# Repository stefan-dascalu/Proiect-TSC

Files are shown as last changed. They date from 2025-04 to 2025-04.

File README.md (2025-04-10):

Dascalu Stefan-Nicolae 331CA
# Proiect-TSC
## Implementare:

- **Implementarea Schemei Electrice:**
  - Am implementat schema electrica exact conform modelului primit.
  - Am efectuat o **verificare a regulilor electrice (ERC)**; desi am intampinat cateva avertismente, le-am revizuit si considerat necritice.

- **Designul PCB:**
  - Dupa finalizarea schemei, am incarcat designul in mediul PCB.
  - Toate componentele au fost amplasate pe **TOP layer** conform ghidurilor de layout.
  - Pentru a asigura **proper grounding** si **signal integrity**, am creat un **GND plane** atat pe TOP layer, cat si pe BOTTOM layer.
  - Am verificat toate constrangerile de design, iar rutarea a fost finalizata cu o rata de succes de 99,6%.
  - In timpul designului PCB, am intampinat si rezolvat erori de tip "airwire unrouted".

- **Fisiere de Productie:**
  - Am generat fisierele **Gerber**, **Pick and Place** si **BOM**.

- **Modelul 3D:**
  - Modelul 3D al dispozitivului a fost implementat.

## Imagine 3D
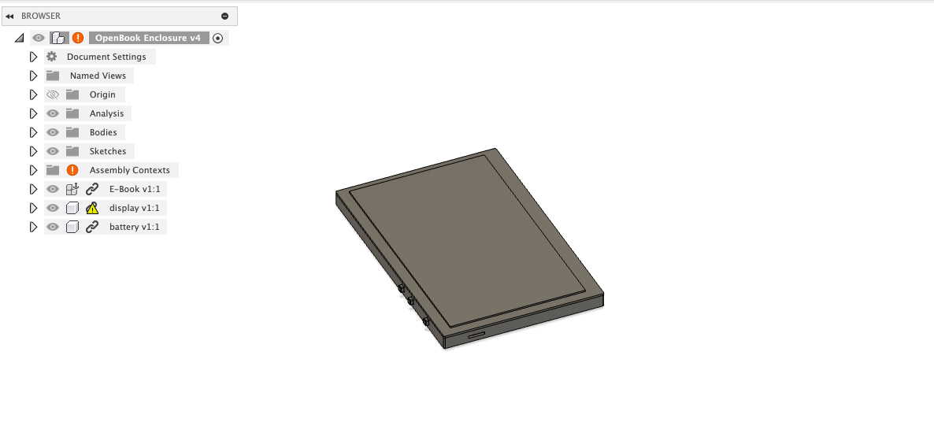
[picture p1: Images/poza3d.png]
Imagine 3D


## Diagrama bloc a proiectului:

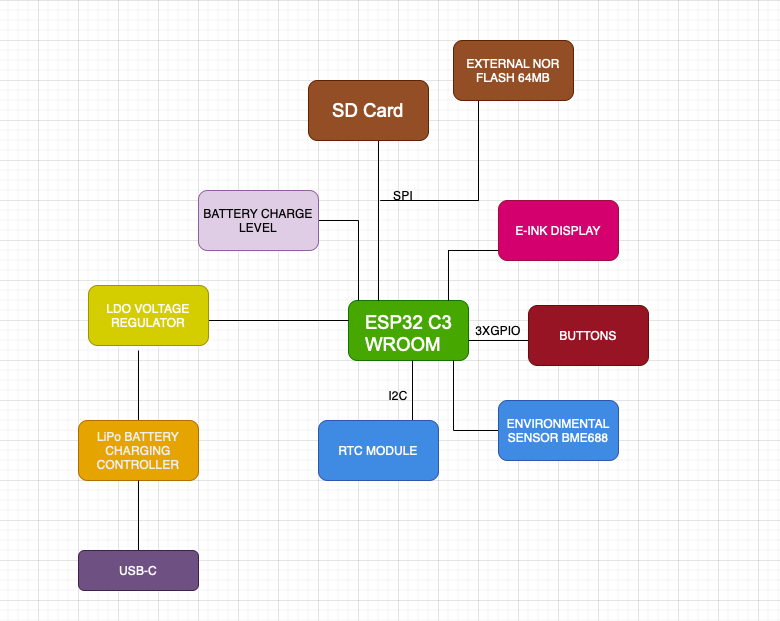
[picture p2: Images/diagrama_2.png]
Diagrama bloc


## Descriere Hardware si Asignarea Pinilor pe ESP32-C6

- **ESP32-C6-WROOM-1-N8 (Microcontroler Principal)**
  - Microcontrolerul ofera suport pentru WiFi 6, Bluetooth 5 LE si dispune de un nucleu RISC-V ce functioneaza pana la 160 MHz.
  - Interfetele disponibile includ SPI, I2C, UART si GPIO, fiind baza pentru conectarea celorlalte module.

- **BME688 (Senzor Ambiental)**
  - Maseaza temperatura, umiditatea, presiunea atmosferica si calitatea aerului.
  - Interfata: I2C
  - Pini utilizati: SDA -> IO21, SCL -> IO22
  - Alegerea acestor pini se face pentru a beneficia de o comunicatie I2C rapida si fiabila.

- **DS3231SN (Real-Time Clock)**
  - Asigura cronometrare de inalta precizie, chiar si in lipsa alimentarii principale.
  - Interfata: I2C (se partajeaza cu BME688)
  - Pini utilizati: SCL -> IO22, SDA -> IO21, INT_RTC -> IO8, 32KHZ -> IO1, RTC_RST -> IO18
  - Acesti pini asigura functii suplimentare de intrerupere si reset pentru modulul RTC.

- **Afisaj E-Ink (7.5 inch)**
  - Afisajul ofera o rezolutie de 800 x 480 pixeli si functioneaza prin interfata SPI.
  - Pini utilizati: EPD_CS -> IO10, EPD_DC -> IO5, EPD_RST -> IO23, EPD_BUSY -> IO3 (EPD_BUSY este partajat cu MISO)
  - Linile MOSI si SCK sunt partajate cu modulul SD, permitand optimizarea numarului de pini utilizati.

- **Modul SD Card**
  - Permite stocarea locala a datelor, cum ar fi e-bookurile sau firmware-ul.
  - Interfata: SPI
  - Pini utilizati: SS_SD -> IO4, MOSI -> IO7, MISO -> IO2, SCK -> IO6
  - Aceste asignari asigura sincronizarea corecta a datelor pe interfata SPI.

- **Memorie Externa Flash (W25Q512JVEIQ, 64MB)**
  - Memoria flash externa este utilizata pentru stocarea firmware-ului si a datelor importante.
  - Interfata: SPI
  - Pini utilizati: FLASH_CS -> IO12 (MOSI, MISO si SCK sunt partajate cu modulul SD)
  
- **Interfata USB/SD**
  - Asigura alimentarea si transferul de date prin USB.
  - Pini utilizati: USB_D+ -> IO13, USB_D- -> IO12

- **Butoane Boot si Reset**
  - Permit accesul la modul boot si efectuarea unui reset hardware.
  - Pini utilizati: IO/BOOT -> IO9, RESET -> un pin dedicat (conform schemei)

- **Sistem de Alimentare si Management**
  - Bateria Li-Po (3.7V, 2500mAh) alimenteaza sistemul.
  - Controlerul de incarcare MCP73831 gestioneaza incarcarea prin USB-C.
  - Monitorizarea bateriei se realizeaza cu MAX17048, care comunica prin I2C (reutilizand SDA/IO21 si SCL/IO22).
  - Regulatorul LDO XC6220A331MR-G furnizeaza 3.3V stabile pentru toate modulele.
  
- **Conector USB-C**
  - Principalul conector pentru alimentare si transfer de date, protejat de circuit ESD.

- **Conector Qwiic/Stemma QT**
  - Permite extinderea usoara a sistemului cu module suplimentare I2C.
  - Utilizeaza acelasi bus I2C (SDA -> IO21, SCL -> IO22) ca si senzorii si modulul RTC.

## BOM:
| Component | Link |
|---|---|
| ADAFRUIT_LEDCHIP-LED0603 | [Click here](https://www.snapeda.com/parts/KP-1608SURCK/Kingbright/view-part/?ref=search&t=LED%200603) |
| SJ | [Click here](https://grabcad.com/library/solder-jumpers-1) |
| 112ATAARR03 | [Click here](https://www.snapeda.com/parts/112A-TAAR-R03/Attend/view-part/) |
| RCL_CPOL-EUCT3528 | [Click here](https://grabcad.com/library/tantalum-smd-capacitor-type-b-3528-1) |
| BUTTON_CUSYOMV1 | [Click here](https://www.snapeda.com/search/?q=EVQP7L01P&search-type=parts) |
| DS3231SN# | [Click here](https://www.snapeda.com/parts/DS3231SN%23/Analog%20Devices/view-part/?ref=search&t=DS3231SN%23) |
| ESP32-C6-WROOM-1-N8 | [Click here](https://www.snapeda.com/parts/ESP32-C6-WROOM-1-N8/Espressif%20Systems/view-part/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) |
| 744043680 | [Click here](https://eu.mouser.com/ProductDetail/Wurth-Elektronik/744043680?qs=PGXP4M47uW6VkZq%252BkzjrHA%3D%3D) |
| BD5229G-TR | [Click here](https://www.snapeda.com/parts/BD5229G-TR/Rohm/view-part/?ref=search&t=BD5229G-TR) |
| ESP32_WROVER_BME680_BME680 | [Click here](https://www.snapeda.com/parts/BME680/Bosch%20Sensortec/view-part/?ref=search&t=bme680) |
| ESP32_WROVER_EAGLE-LTSPICE_R | [Click here](https://componentsearchengine.com/part-view/R0402%201%25%20100%20K%20(RC0402FR-07100KL)/YAGEO) |
| ESP32_WROVER_SPARKFUN-DISCRETESEMI_MOSFET_PCH | [Click here](https://componentsearchengine.com/part-view/DMG2305UX-7/Diodes%20Incorporated) |
| ESP32_WROVER_SPARKFUN-IC-POWER_MCP73831 | [Click here](https://componentsearchengine.com/part-view/MCP73831T-2ACI%2FOT/Microchip) |
| FH34SRJ-24S-0.5SH_99_ | [Click here](https://componentsearchengine.com/part-view/FH34SRJ-24S-0.5SH(99)/Hirose) |
| TP | - |
| SI1308EDL-T1-GE3 | [Click here](https://www.snapeda.com/parts/SI1308EDL-T1-GE3/Vishay/view-part/) |
| ESP32_WROVER_AVX---SD0805S020S1R0_AVX_SD0805S020S1R0_0_0  | [Click here](https://componentsearchengine.com/part-view/SD0805S020S1R0/Kyocera%20AVX) |
| CPH3225A | [Click here](https://www.snapeda.com/parts/CPH3225A/Seiko/view-part/) |
| MAX17048G+T10 | [Click here](https://www.snapeda.com/parts/MAX17048G+T10/Analog%20Devices/view-part/) |
| MBR0530 | [Click here](https://www.snapeda.com/parts/MBR0530/Onsemi/view-part/) |
| PGB1010603MR | [Click here](https://www.snapeda.com/parts/PGB1010603MR/Littelfuse/view-part/) |
| QWIIC_RIGHT_ANGLE (QWIIC_CONNECTORJS-1MM) | [Click here](https://www.snapeda.com/parts/PRT-14417/SparkFun/view-part/) |
| SAMACSYS_PARTS_USB4110-GF-A | [Click here](https://www.snapeda.com/parts/USB4110-GF-A./Global%20Connector%20Technology/view-part/) |
| USBLC6-2SC6Y | [Click here](https://www.snapeda.com/parts/USBLC6-2SC6Y/STMicroelectronics/view-part/?ref=dk&t=USBLC6-2SC6Y&con_ref=None) |
| W25Q512JVEIQ | [Click here](https://www.snapeda.com/parts/W25Q512JVEIQ/Winbond%20Electronics/view-part/?ref=search&t=W25Q512JVEIQ) |
| XC6220A331MR-G | [Click here](https://ro.mouser.com/ProductDetail/Torex-Semiconductor/XC6220A331MR-G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) |

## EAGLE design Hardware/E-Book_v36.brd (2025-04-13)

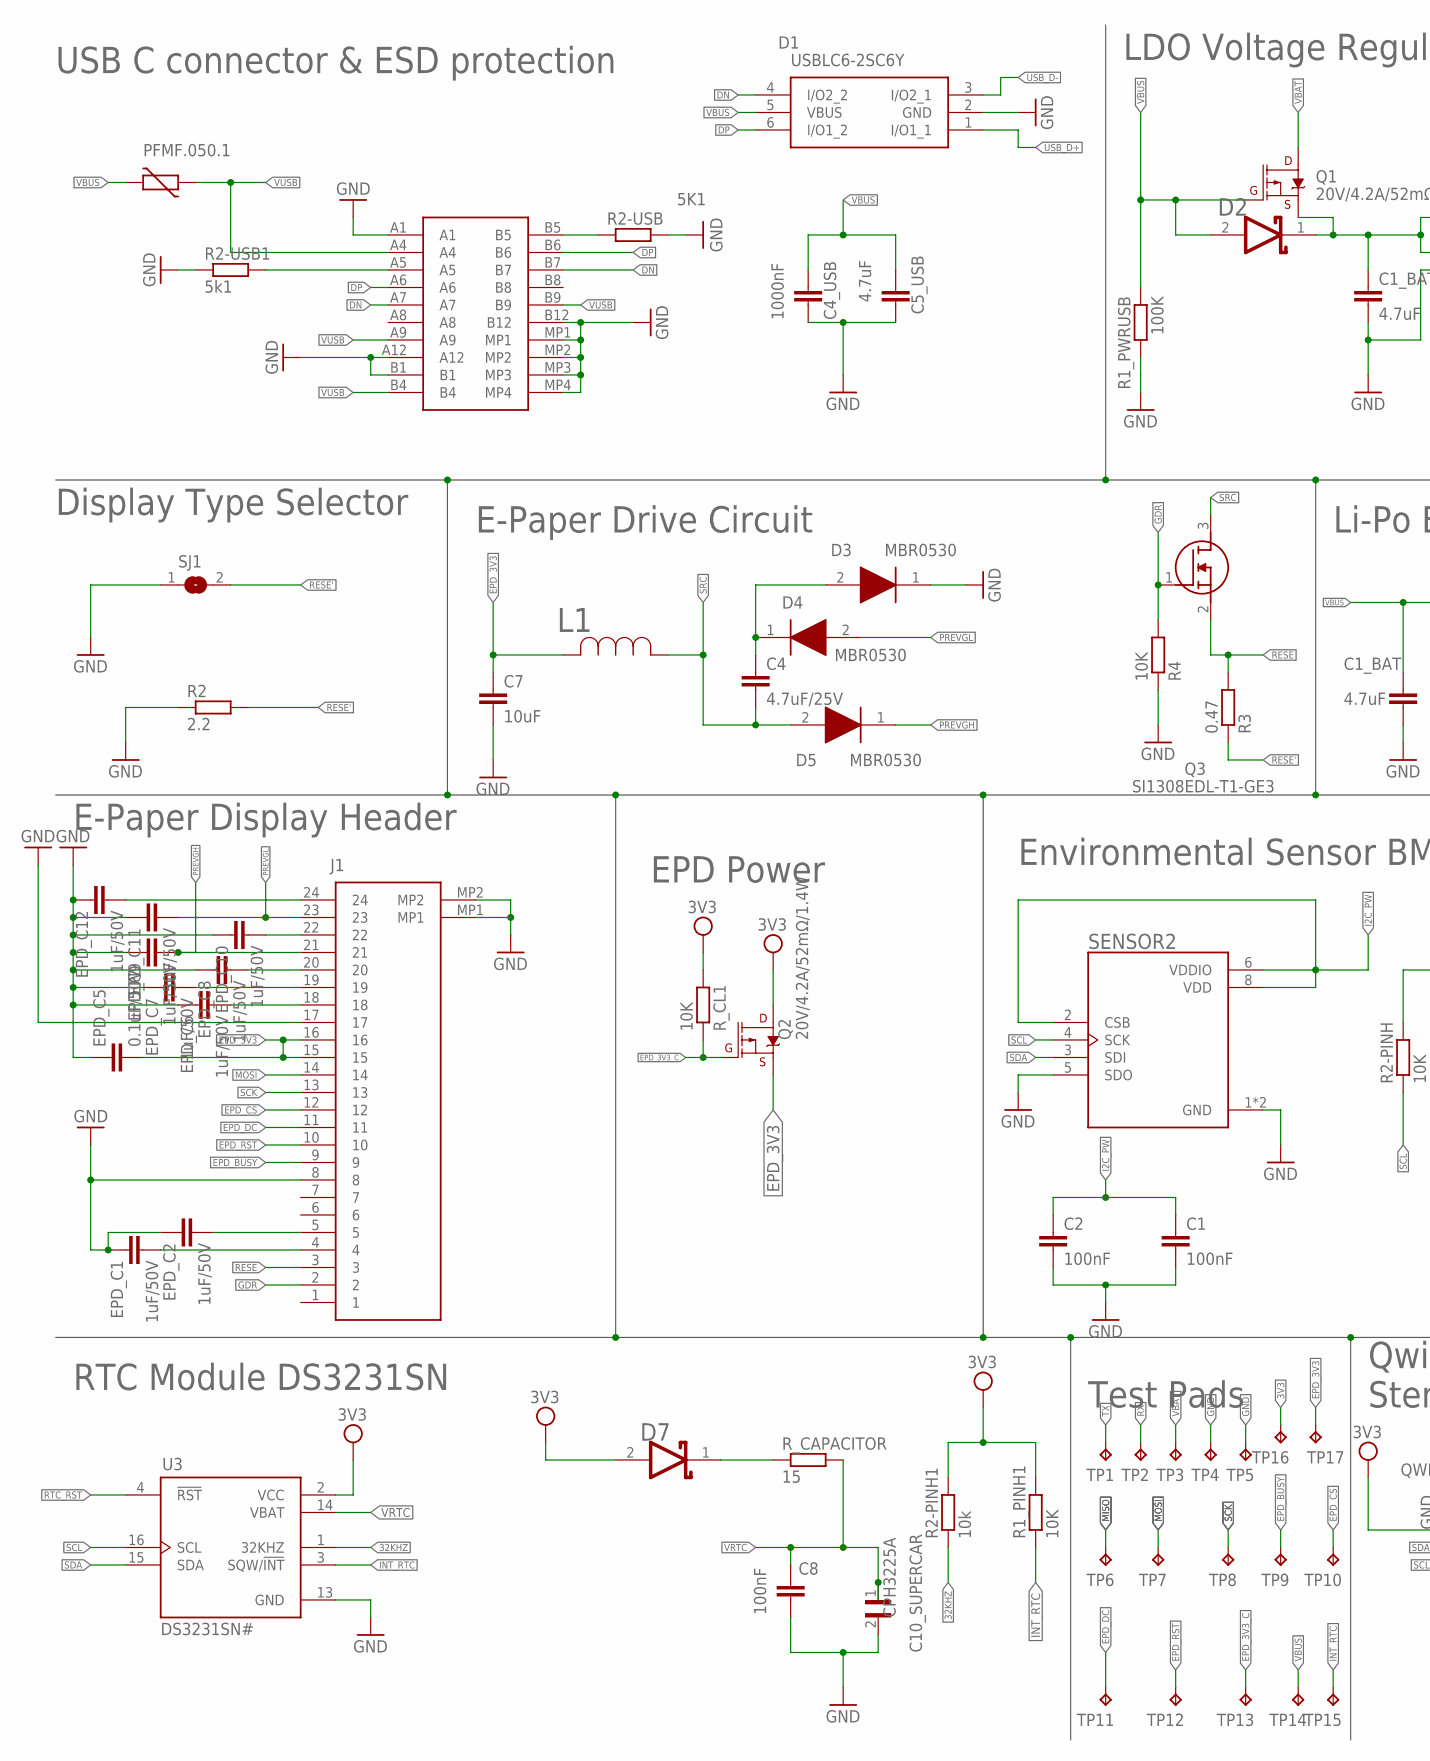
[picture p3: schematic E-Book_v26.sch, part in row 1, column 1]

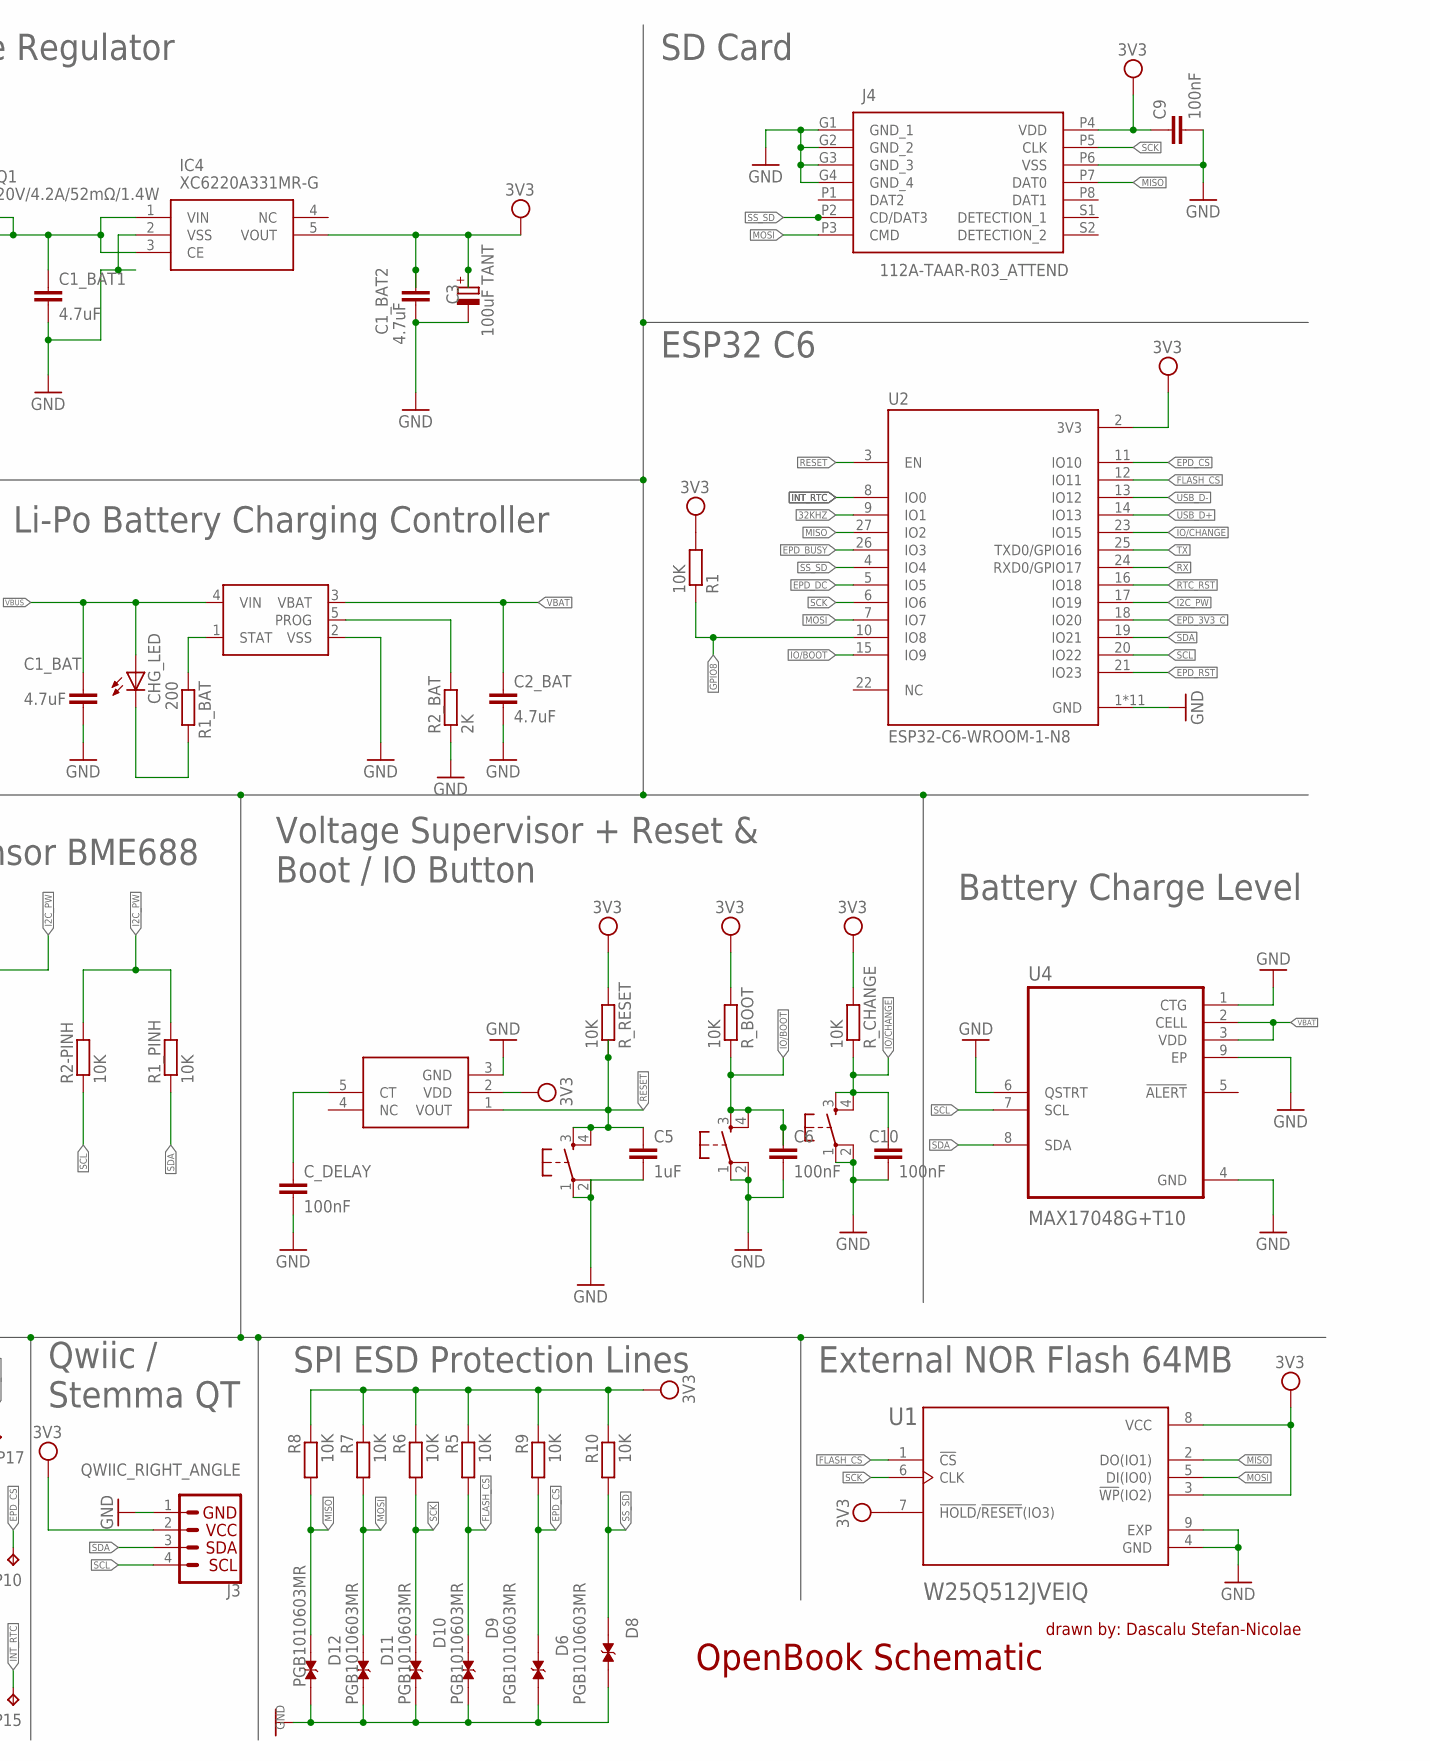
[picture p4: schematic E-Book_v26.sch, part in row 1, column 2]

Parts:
C1, C2, C6, C8, C9, C10: 100nF; ESP32_WROVER_EAGLE-LTSPICE_C0402
C1_BAT, C2_BAT: 4.7uF; ESP32_WROVER_EAGLE-LTSPICE_C0402
C1_BAT1, C1_BAT2, C5_USB: 4.7uF; EAGLE-LTSPICE_C0402
C3: 100uF TANT; RCL_CT3528
C4: 4.7uF/25V; ESP32_WROVER_EAGLE-LTSPICE_C0402
C4_USB: 1000nF; EAGLE-LTSPICE_C0402
C5: 1uF; ESP32_WROVER_EAGLE-LTSPICE_C0402
C7: 10uF; ESP32_WROVER_EAGLE-LTSPICE_C0402
C10_SUPERCAR: CPH3225A; CAPCP3225X100N
CHG_LED: ADAFRUIT_LEDCHIP-LED0603; ADAFRUIT_CHIP-LED0603
C_DELAY: 100nF; ESP32_WROVER_EAGLE-LTSPICE_C0402
D1: USBLC6-2SC6Y; SOT95P280X145-6N
D2, D7: ESP32_WROVER_AVX---SD0805S020S1R0_AVX_SD0805S020S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; ESP32_WROVER_AVX---SD0805S020S1R0_AVX_SD0805S020S1R0_0
D3, D4, D5: MBR0530; SOD3716X135N
D6, D8, D9, D10, D11, D12: PGB1010603MR; DIOC1608X36N
EPD_C1, EPD_C2, EPD_C6, EPD_C7, EPD_C8, EPD_C9, EPD_C10, EPD_C11, EPD_C12: 1uF/50V; ESP32_WROVER_EAGLE-LTSPICE_C0402
EPD_C5: 0.1uF/50V; ESP32_WROVER_EAGLE-LTSPICE_C0402
IC1: BD5229G-TR; SOT95P280X125-5N
IC4: XC6220A331MR-G; SOT95P280X120-5N
J1: FH34SRJ-24S-0.5SH_99_; FH34SRJ24S05SH99
J2: SAMACSYS_PARTS_USB4110-GF-A; SAMACSYS_PARTS_USB4110GFA
J3: QWIIC_RIGHT_ANGLE; JST04_1MM_RA
J4: 112A-TAAR-R03_ATTEND; 112ATAARR03ATTEND
L1: 744043680IND_4828-WE-TPC_WRE; IND_4828-WE-TPC_WRE
MCP73831: ESP32_WROVER_SPARKFUN-IC-POWER_MCP73831; ESP32_WROVER_SPARKFUN-IC-POWER_SOT23-5
PFMF.050.1: ESP32C6_VARISTORCN1812; ESP32C6_VARISTOR_CT/CN1812
Q1, Q2: 20V/4.2A/52mΩ/1.4W; ESP32_WROVER_SPARKFUN-DISCRETESEMI_SOT23-3
Q3: SI1308EDL-T1-GE3; SOT65P210X110-3N
R1, R1_PINH, R1_PINH1, R2-PINH, R4, R5, R6, R7, R8, R9, R10: 10K; ESP32_WROVER_EAGLE-LTSPICE_R0402
R1_BAT: 200; ESP32_WROVER_EAGLE-LTSPICE_R0402
R1_PWRUSB: 100K; ESP32_WROVER_EAGLE-LTSPICE_R0402
R2: 2.2; ESP32_WROVER_EAGLE-LTSPICE_R0402
R2-PINH1: 10k; ESP32_WROVER_EAGLE-LTSPICE_R0402
R2-USB: 5K1; ESP32_WROVER_EAGLE-LTSPICE_R0402
R2-USB1: 5k1; ESP32_WROVER_EAGLE-LTSPICE_R0402
R2_BAT: 2K; ESP32_WROVER_EAGLE-LTSPICE_R0402
R3: 0.47; ESP32_WROVER_EAGLE-LTSPICE_R0402
RESET_BUTTON: BUTTON_CUSYOMV1; MYBUTTON
R_BOOT: 10K; ESP32_WROVER_EAGLE-LTSPICE_R0402
R_CAPACITOR: 15; ESP32_WROVER_EAGLE-LTSPICE_R0402
R_CHANGE: 10K; ESP32_WROVER_EAGLE-LTSPICE_R0402
R_CL1: 10K; ESP32_WROVER_EAGLE-LTSPICE_R0402
R_RESET: 10K; ESP32_WROVER_EAGLE-LTSPICE_R0402
SENSOR2: ESP32_WROVER_BME680_BME680; ESP32_WROVER_BME680_PSON80P300X300X100-8N
SJ1: SJ
TP1, TP2, TP3, TP4, TP5, TP6, TP7, TP8, TP9, TP10, TP11, TP12, TP13, TP14, TP15, TP16, TP17: TPTP20R; TP20R
U1: W25Q512JVEIQ; SON127P600X800X80-9N
U2: ESP32-C6-WROOM-1-N8; XCVR_ESP32-C6-WROOM-1-N8
U3: DS3231SN#; SOIC127P1032X265-16N
U4: MAX17048G+T10; SON50P200X200X80-9N
U$1, U$3: BUTTON_CUSYOMV1; MYBUTTON

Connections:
3V3: C1_BAT2.1, C3.+, C9.1, D7.2 (ANODE), IC1.2 (VDD), IC4.5 (VOUT), J3.2, J4.P4 (VDD), Q2.3 (D), R1.2, R1_PINH1.2, R2-PINH1.2, R5.1, R6.1, R7.1, R8.1, R9.1, R10.1, R_BOOT.2, R_CHANGE.2, R_CL1.2, R_RESET.2, TP16.TP, U1.3 (!WP!(IO2)), U1.7 (!HOLD!/!RESET!(IO3)), U1.8 (VCC), U2.2 (3V3), U3.2 (VCC)
32KHZ: R2-PINH1.1, U2.9 (IO1), U3.1 (32KHZ)
DN: D1.4 (I/O2_2), J2.A7, J2.B7
DP: D1.6 (I/O1_2), J2.A6, J2.B6
EPD_3V3: C7.1, EPD_C5.2, J1.15, J1.16, L1.2, Q2.2 (S), TP17.TP
EPD_3V3_C: Q2.1 (G), R_CL1.1, TP13.TP, U2.18 (IO20)
EPD_BUSY: J1.9, TP9.TP, U2.26 (IO3)
EPD_CS: D6.1, J1.12, R9.2, TP10.TP, U2.11 (IO10)
EPD_DC: J1.11, TP11.TP, U2.5 (IO5)
EPD_RST: J1.10, TP12.TP, U2.21 (IO23)
FLASH_CS: D9.1, R5.2, U1.1 (!CS), U2.12 (IO11)
GDR: J1.2, Q3.1 (G), R4.2
GND: C1.2, C1_BAT.2, C1_BAT1.2, C1_BAT2.2, C2.2, C2_BAT.2, C3.-, C4_USB.2, C5.2, C5_USB.2, C6.2, C7.2, C8.2, C9.2, C10.2, C10_SUPERCAR.2, C_DELAY.2, D1.2 (GND), D3.1 (K), D6.2, D8.2, D9.2, D10.2, D11.2, D12.2, EPD_C1.1, EPD_C2.1, EPD_C5.1, EPD_C6.1, EPD_C7.1, EPD_C8.1, EPD_C9.1, EPD_C10.1, EPD_C11.1, EPD_C12.1, IC1.3 (GND), IC4.2 (VSS), J1.8, J1.17, J1.MP1, J1.MP2, J2.A1, J2.A12, J2.B1, J2.B12, J2.MP1, J2.MP2, J2.MP3, J2.MP4, J3.1, J4.G1 (GND_1), J4.G2 (GND_2), J4.G3 (GND_3), J4.G4 (GND_4), J4.P6 (VSS), MCP73831.2 (VSS), R1_PWRUSB.2, R2.1, R2-USB.2, R2-USB1.1, R2_BAT.1, R4.1, RESET_BUTTON.1, RESET_BUTTON.2, SENSOR2.1 (GND), SENSOR2.5 (SDO), SENSOR2.7 (GND), SJ1.1, TP4.TP, TP5.TP, U1.4 (GND), U1.9 (EXP), U2.1 (GND), U2.28 (GND), U2.29_1 (GND), U2.29_2 (GND), U2.29_3 (GND), U2.29_4 (GND), U2.29_5 (GND), U2.29_6 (GND), U2.29_7 (GND), U2.29_8 (GND), U2.29_9 (GND), U3.13 (GND), U4.1 (CTG), U4.4 (GND), U4.6 (QSTRT), U4.9 (EP), U$1.1, U$1.2, U$3.1, U$3.2
GPIO8: R1.1, U2.10 (IO8)
I2C_PW: C1.1, C2.1, R1_PINH.2, R2-PINH.2, SENSOR2.2 (CSB), SENSOR2.6 (VDDIO), SENSOR2.8 (VDD), U2.17 (IO19)
INT_RTC: R1_PINH1.1, TP15.TP, U2.8 (IO0), U3.3 (SQW/!INT)
IO/BOOT: C6.1, R_BOOT.1, U2.15 (IO9), U$3.3, U$3.4
IO/CHANGE: C10.1, R_CHANGE.1, U2.23 (IO15), U$1.3, U$1.4
MISO: D12.1, J4.P7 (DAT0), R8.2, TP6.TP, U1.2 (DO(IO1)), U2.27 (IO2)
MOSI: D11.1, J1.14, J4.P3 (CMD), R7.2, TP7.TP, U1.5 (DI(IO0)), U2.7 (IO7)
unnamed: J2.B5, R2-USB.1
unnamed: J2.A5, R2-USB1.2
unnamed: CHG_LED.C, R1_BAT.2
unnamed: EPD_C1.2, J1.4
unnamed: MCP73831.5 (PROG), R2_BAT.2
unnamed: EPD_C2.2, J1.5
unnamed: MCP73831.1 (STAT), R1_BAT.1
unnamed: EPD_C6.2, J1.18
unnamed: EPD_C7.2, J1.19
unnamed: EPD_C8.2, J1.20
unnamed: EPD_C10.2, J1.22
unnamed: EPD_C12.2, J1.24
unnamed: C_DELAY.1, IC1.5 (CT)
unnamed: C1_BAT1.1, D2.1 (CATHODE), IC4.1 (VIN), IC4.3 (CE), Q1.2 (S)
unnamed: C4.1, D3.2 (A), D4.1 (K)
unnamed: D7.1 (CATHODE), R_CAPACITOR.1
PREVGH: D5.1 (K), EPD_C9.2, J1.21
PREVGL: D4.2 (A), EPD_C11.2, J1.23
RESE: J1.3, Q3.2 (S), R3.2
RESE': R2.2, R3.1, SJ1.2
RESET: C5.1, IC1.1 (VOUT), RESET_BUTTON.3, RESET_BUTTON.4, R_RESET.1, U2.3 (EN)
RTC_RST: U2.16 (IO18), U3.4 (!RST)
RX: TP2.TP, U2.24 (RXD0/GPIO17)
SCK: D10.1, J1.13, J4.P5 (CLK), R6.2, TP8.TP, U1.6 (CLK), U2.6 (IO6)
SCL: J3.4, R2-PINH.1, SENSOR2.4 (SCK), U2.20 (IO22), U3.16 (SCL), U4.7 (SCL)
SDA: J3.3, R1_PINH.1, SENSOR2.3 (SDI), U2.19 (IO21), U3.15 (SDA), U4.8 (SDA)
SRC: C4.2, D5.2 (A), L1.1, Q3.3 (D)
SS_SD: D8.1, J4.P2 (CD/DAT3), R10.2, U2.4 (IO4)
TX: TP1.TP, U2.25 (TXD0/GPIO16)
USB_D+: D1.1 (I/O1_1), U2.14 (IO13)
USB_D-: D1.3 (I/O2_1), U2.13 (IO12)
VBAT: C2_BAT.1, MCP73831.3 (VBAT), Q1.3 (D), TP3.TP, U4.2 (CELL), U4.3 (VDD)
VBUS: C1_BAT.1, C4_USB.1, C5_USB.1, CHG_LED.A, D1.5 (VBUS), D2.2 (ANODE), MCP73831.4 (VIN), PFMF.050.1.2, Q1.1 (G), R1_PWRUSB.1, TP14.TP
VRTC: C8.1, C10_SUPERCAR.1, R_CAPACITOR.2, U3.14 (VBAT)
VUSB: J2.A4, J2.A9, J2.B4, J2.B9, PFMF.050.1.1

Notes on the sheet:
USB C connector & ESD protection
Display Type Selector
Test Pads
Qwiic / Stemma QT
External NOR Flash 64MB
drawn by: Dascalu Stefan-Nicolae
Battery Charge Level
OpenBook Schematic
EPD Power
Environmental Sensor BME688
SD Card
ESP32 C6
Li-Po Battery Charging Controller
E-Paper Display Header
SPI ESD Protection Lines
LDO Voltage Regulator
Voltage Supervisor + Reset & Boot / IO Button
E-Paper Drive Circuit
RTC Module DS3231SN


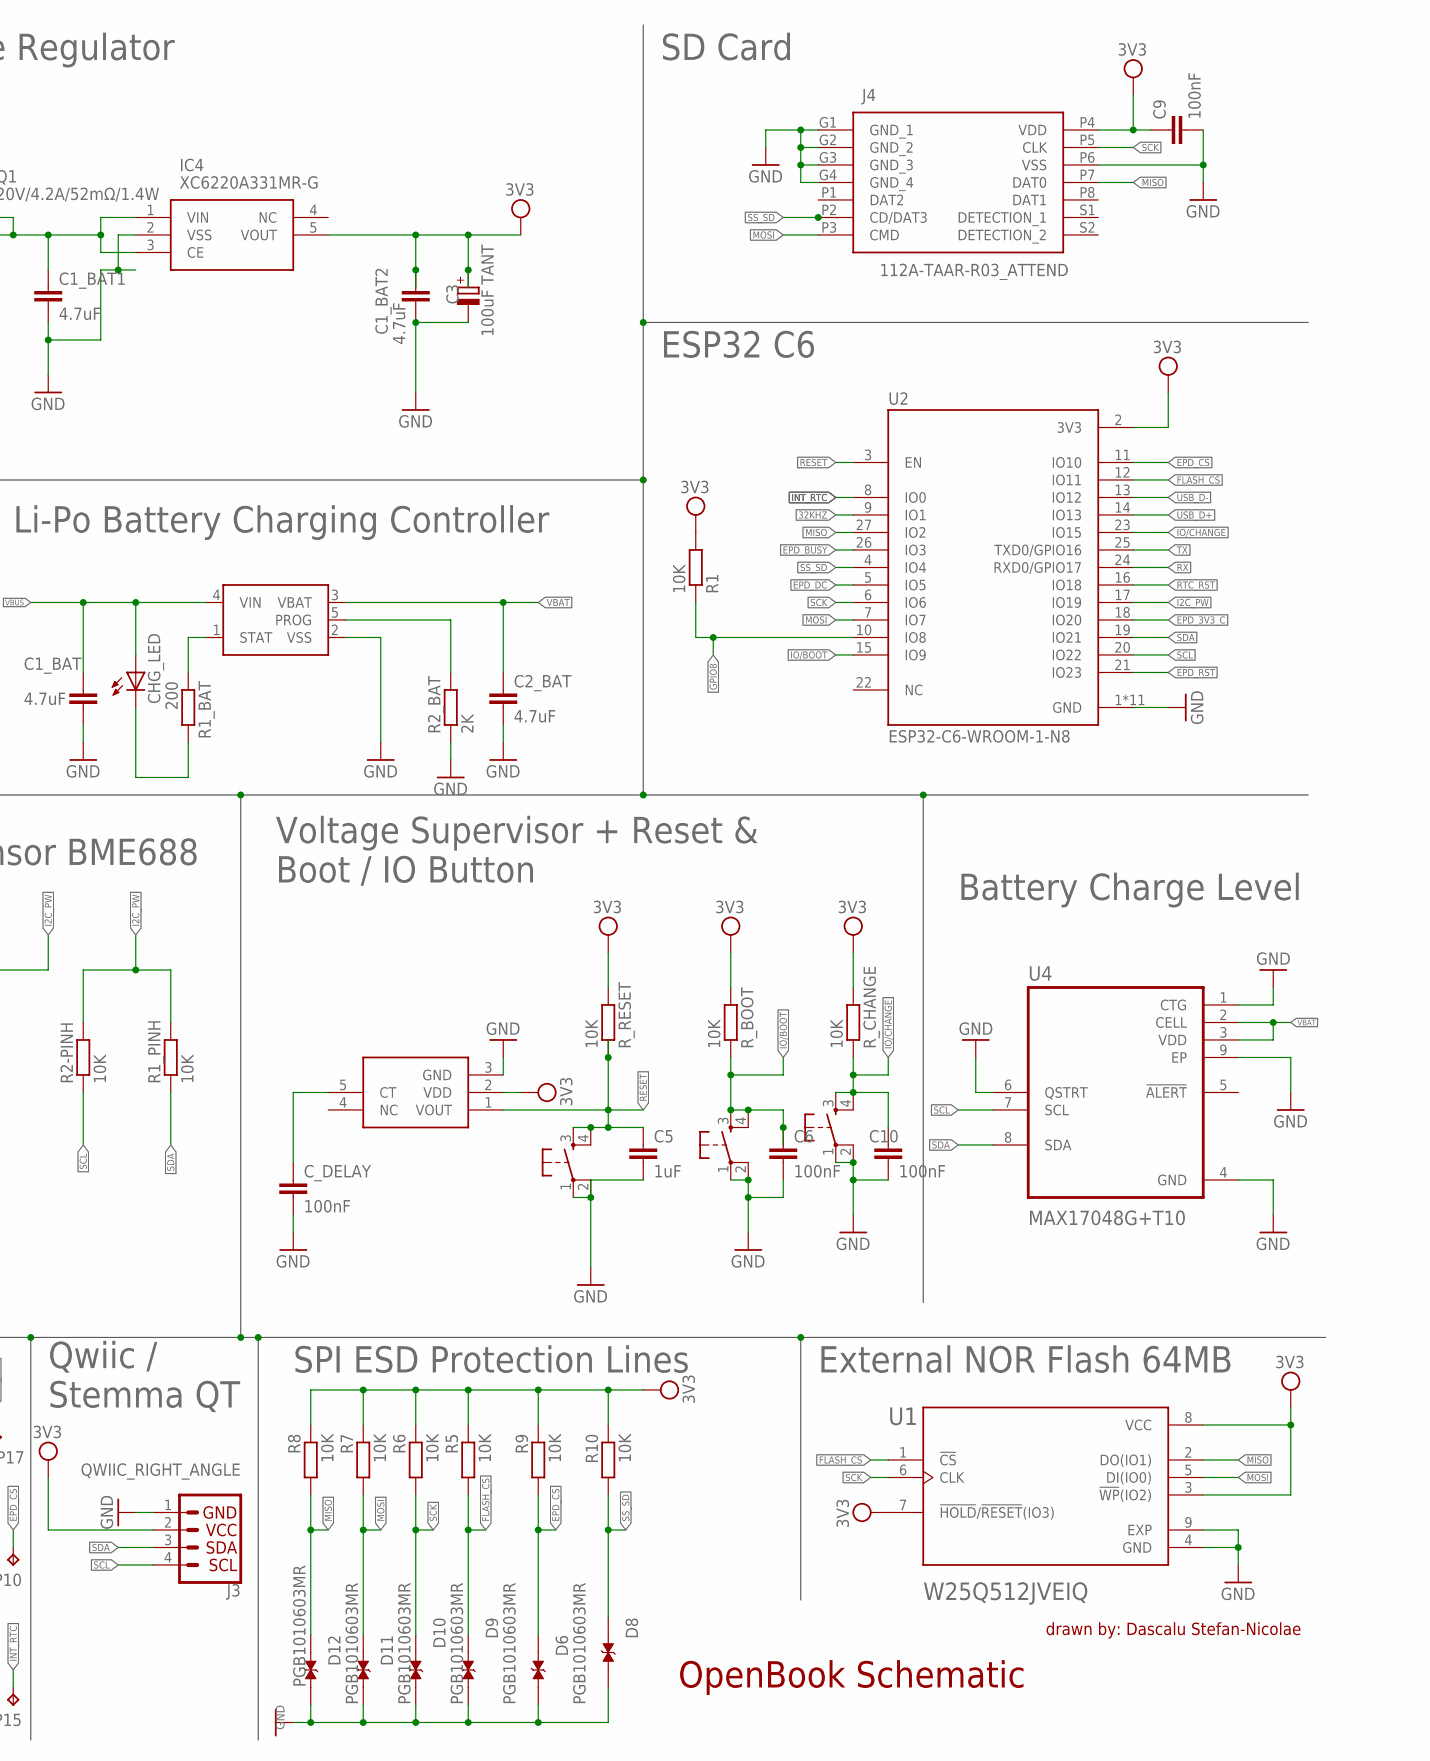
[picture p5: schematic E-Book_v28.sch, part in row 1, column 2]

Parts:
C1, C2, C6, C8, C9, C10: 100nF; ESP32_WROVER_EAGLE-LTSPICE_C0402
C1_BAT, C2_BAT: 4.7uF; ESP32_WROVER_EAGLE-LTSPICE_C0402
C1_BAT1, C1_BAT2, C5_USB: 4.7uF; EAGLE-LTSPICE_C0402
C3: 100uF TANT; RCL_CT3528
C4: 4.7uF/25V; ESP32_WROVER_EAGLE-LTSPICE_C0402
C4_USB: 1000nF; EAGLE-LTSPICE_C0402
C5: 1uF; ESP32_WROVER_EAGLE-LTSPICE_C0402
C7: 10uF; ESP32_WROVER_EAGLE-LTSPICE_C0402
C10_SUPERCAR: CPH3225A; CAPCP3225X100N
CHG_LED: ADAFRUIT_LEDCHIP-LED0603; ADAFRUIT_CHIP-LED0603
C_DELAY: 100nF; ESP32_WROVER_EAGLE-LTSPICE_C0402
D1: USBLC6-2SC6Y; SOT95P280X145-6N
D2, D7: ESP32_WROVER_AVX---SD0805S020S1R0_AVX_SD0805S020S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; ESP32_WROVER_AVX---SD0805S020S1R0_AVX_SD0805S020S1R0_0
D3, D4, D5: MBR0530; SOD3716X135N
D6, D8, D9, D10, D11, D12: PGB1010603MR; DIOC1608X36N
EPD_C1, EPD_C2, EPD_C6, EPD_C7, EPD_C8, EPD_C9, EPD_C10, EPD_C11, EPD_C12: 1uF/50V; ESP32_WROVER_EAGLE-LTSPICE_C0402
EPD_C5: 0.1uF/50V; ESP32_WROVER_EAGLE-LTSPICE_C0402
IC1: BD5229G-TR; SOT95P280X125-5N
IC4: XC6220A331MR-G; SOT95P280X120-5N
J1: FH34SRJ-24S-0.5SH_99_; FH34SRJ24S05SH99
J2: SAMACSYS_PARTS_USB4110-GF-A; SAMACSYS_PARTS_USB4110GFA
J3: QWIIC_RIGHT_ANGLE; JST04_1MM_RA
J4: 112A-TAAR-R03_ATTEND; 112ATAARR03ATTEND
L1: 744043680IND_4828-WE-TPC_WRE; IND_4828-WE-TPC_WRE
MCP73831: ESP32_WROVER_SPARKFUN-IC-POWER_MCP73831; ESP32_WROVER_SPARKFUN-IC-POWER_SOT23-5
PFMF.050.1: ESP32C6_VARISTORCN1812; ESP32C6_VARISTOR_CT/CN1812
Q1, Q2: 20V/4.2A/52mΩ/1.4W; ESP32_WROVER_SPARKFUN-DISCRETESEMI_SOT23-3
Q3: SI1308EDL-T1-GE3; SOT65P210X110-3N
R1, R1_PINH, R1_PINH1, R2-PINH, R4, R5, R6, R7, R8, R9, R10: 10K; ESP32_WROVER_EAGLE-LTSPICE_R0402
R1_BAT: 200; ESP32_WROVER_EAGLE-LTSPICE_R0402
R1_PWRUSB: 100K; ESP32_WROVER_EAGLE-LTSPICE_R0402
R2: 2.2; ESP32_WROVER_EAGLE-LTSPICE_R0402
R2-PINH1: 10k; ESP32_WROVER_EAGLE-LTSPICE_R0402
R2-USB: 5K1; ESP32_WROVER_EAGLE-LTSPICE_R0402
R2-USB1: 5k1; ESP32_WROVER_EAGLE-LTSPICE_R0402
R2_BAT: 2K; ESP32_WROVER_EAGLE-LTSPICE_R0402
R3: 0.47; ESP32_WROVER_EAGLE-LTSPICE_R0402
RESET_BUTTON: BUTTON_CUSYOMV1; MYBUTTON
R_BOOT: 10K; ESP32_WROVER_EAGLE-LTSPICE_R0402
R_CAPACITOR: 15; ESP32_WROVER_EAGLE-LTSPICE_R0402
R_CHANGE: 10K; ESP32_WROVER_EAGLE-LTSPICE_R0402
R_CL1: 10K; ESP32_WROVER_EAGLE-LTSPICE_R0402
R_RESET: 10K; ESP32_WROVER_EAGLE-LTSPICE_R0402
SENSOR2: ESP32_WROVER_BME680_BME680; ESP32_WROVER_BME680_PSON80P300X300X100-8N
SJ1: SJ
TP1, TP2, TP3, TP4, TP5, TP6, TP7, TP8, TP9, TP10, TP11, TP12, TP13, TP14, TP15, TP16, TP17: TPTP20R; TP20R
U1: W25Q512JVEIQ; SON127P600X800X80-9N
U2: ESP32-C6-WROOM-1-N8; XCVR_ESP32-C6-WROOM-1-N8
U3: DS3231SN#; SOIC127P1032X265-16N
U4: MAX17048G+T10; SON50P200X200X80-9N
U$1, U$3: BUTTON_CUSYOMV1; MYBUTTON

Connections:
3V3: C1_BAT2.1, C3.+, C9.1, D7.2 (ANODE), IC1.2 (VDD), IC4.5 (VOUT), J3.2, J4.P4 (VDD), Q2.3 (D), R1.2, R1_PINH1.2, R2-PINH1.2, R5.1, R6.1, R7.1, R8.1, R9.1, R10.1, R_BOOT.2, R_CHANGE.2, R_CL1.2, R_RESET.2, TP16.TP, U1.3 (!WP!(IO2)), U1.7 (!HOLD!/!RESET!(IO3)), U1.8 (VCC), U2.2 (3V3), U3.2 (VCC)
32KHZ: R2-PINH1.1, U2.9 (IO1), U3.1 (32KHZ)
DN: D1.4 (I/O2_2), J2.A7, J2.B7
DP: D1.6 (I/O1_2), J2.A6, J2.B6
EPD_3V3: C7.1, EPD_C5.2, J1.15, J1.16, L1.2, Q2.2 (S), TP17.TP
EPD_3V3_C: Q2.1 (G), R_CL1.1, TP13.TP, U2.18 (IO20)
EPD_BUSY: J1.9, TP9.TP, U2.26 (IO3)
EPD_CS: D6.1, J1.12, R9.2, TP10.TP, U2.11 (IO10)
EPD_DC: J1.11, TP11.TP, U2.5 (IO5)
EPD_RST: J1.10, TP12.TP, U2.21 (IO23)
FLASH_CS: D9.1, R5.2, U1.1 (!CS), U2.12 (IO11)
GDR: J1.2, Q3.1 (G), R4.2
GND: C1.2, C1_BAT.2, C1_BAT1.2, C1_BAT2.2, C2.2, C2_BAT.2, C3.-, C4_USB.2, C5.2, C5_USB.2, C6.2, C7.2, C8.2, C9.2, C10.2, C10_SUPERCAR.2, C_DELAY.2, D1.2 (GND), D3.1 (K), D6.2, D8.2, D9.2, D10.2, D11.2, D12.2, EPD_C1.1, EPD_C2.1, EPD_C5.1, EPD_C6.1, EPD_C7.1, EPD_C8.1, EPD_C9.1, EPD_C10.1, EPD_C11.1, EPD_C12.1, IC1.3 (GND), IC4.2 (VSS), J1.8, J1.17, J1.MP1, J1.MP2, J2.A1, J2.A12, J2.B1, J2.B12, J2.MP1, J2.MP2, J2.MP3, J2.MP4, J3.1, J4.G1 (GND_1), J4.G2 (GND_2), J4.G3 (GND_3), J4.G4 (GND_4), J4.P6 (VSS), MCP73831.2 (VSS), R1_PWRUSB.2, R2.1, R2-USB.2, R2-USB1.1, R2_BAT.1, R4.1, RESET_BUTTON.1, RESET_BUTTON.2, SENSOR2.1 (GND), SENSOR2.5 (SDO), SENSOR2.7 (GND), SJ1.1, TP4.TP, TP5.TP, U1.4 (GND), U1.9 (EXP), U2.1 (GND), U2.28 (GND), U2.29_1 (GND), U2.29_2 (GND), U2.29_3 (GND), U2.29_4 (GND), U2.29_5 (GND), U2.29_6 (GND), U2.29_7 (GND), U2.29_8 (GND), U2.29_9 (GND), U3.13 (GND), U4.1 (CTG), U4.4 (GND), U4.6 (QSTRT), U4.9 (EP), U$1.1, U$1.2, U$3.1, U$3.2
GPIO8: R1.1, U2.10 (IO8)
I2C_PW: C1.1, C2.1, R1_PINH.2, R2-PINH.2, SENSOR2.2 (CSB), SENSOR2.6 (VDDIO), SENSOR2.8 (VDD), U2.17 (IO19)
INT_RTC: R1_PINH1.1, TP15.TP, U2.8 (IO0), U3.3 (SQW/!INT)
IO/BOOT: C6.1, R_BOOT.1, U2.15 (IO9), U$3.3, U$3.4
IO/CHANGE: C10.1, R_CHANGE.1, U2.23 (IO15), U$1.3, U$1.4
MISO: D12.1, J4.P7 (DAT0), R8.2, TP6.TP, U1.2 (DO(IO1)), U2.27 (IO2)
MOSI: D11.1, J1.14, J4.P3 (CMD), R7.2, TP7.TP, U1.5 (DI(IO0)), U2.7 (IO7)
unnamed: J2.B5, R2-USB.1
unnamed: J2.A5, R2-USB1.2
unnamed: CHG_LED.C, R1_BAT.2
unnamed: EPD_C1.2, J1.4
unnamed: MCP73831.5 (PROG), R2_BAT.2
unnamed: EPD_C2.2, J1.5
unnamed: MCP73831.1 (STAT), R1_BAT.1
unnamed: EPD_C6.2, J1.18
unnamed: EPD_C7.2, J1.19
unnamed: EPD_C8.2, J1.20
unnamed: EPD_C10.2, J1.22
unnamed: EPD_C12.2, J1.24
unnamed: C_DELAY.1, IC1.5 (CT)
unnamed: C1_BAT1.1, D2.1 (CATHODE), IC4.1 (VIN), IC4.3 (CE), Q1.2 (S)
unnamed: C4.1, D3.2 (A), D4.1 (K)
unnamed: D7.1 (CATHODE), R_CAPACITOR.1
PREVGH: D5.1 (K), EPD_C9.2, J1.21
PREVGL: D4.2 (A), EPD_C11.2, J1.23
RESE: J1.3, Q3.2 (S), R3.2
RESE': R2.2, R3.1, SJ1.2
RESET: C5.1, IC1.1 (VOUT), RESET_BUTTON.3, RESET_BUTTON.4, R_RESET.1, U2.3 (EN)
RTC_RST: U2.16 (IO18), U3.4 (!RST)
RX: TP2.TP, U2.24 (RXD0/GPIO17)
SCK: D10.1, J1.13, J4.P5 (CLK), R6.2, TP8.TP, U1.6 (CLK), U2.6 (IO6)
SCL: J3.4, R2-PINH.1, SENSOR2.4 (SCK), U2.20 (IO22), U3.16 (SCL), U4.7 (SCL)
SDA: J3.3, R1_PINH.1, SENSOR2.3 (SDI), U2.19 (IO21), U3.15 (SDA), U4.8 (SDA)
SRC: C4.2, D5.2 (A), L1.1, Q3.3 (D)
SS_SD: D8.1, J4.P2 (CD/DAT3), R10.2, U2.4 (IO4)
TX: TP1.TP, U2.25 (TXD0/GPIO16)
USB_D+: D1.1 (I/O1_1), U2.14 (IO13)
USB_D-: D1.3 (I/O2_1), U2.13 (IO12)
VBAT: C2_BAT.1, MCP73831.3 (VBAT), Q1.3 (D), TP3.TP, U4.2 (CELL), U4.3 (VDD)
VBUS: C1_BAT.1, C4_USB.1, C5_USB.1, CHG_LED.A, D1.5 (VBUS), D2.2 (ANODE), MCP73831.4 (VIN), PFMF.050.1.2, Q1.1 (G), R1_PWRUSB.1, TP14.TP
VRTC: C8.1, C10_SUPERCAR.1, R_CAPACITOR.2, U3.14 (VBAT)
VUSB: J2.A4, J2.A9, J2.B4, J2.B9, PFMF.050.1.1

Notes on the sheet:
USB C connector & ESD protection
Display Type Selector
Test Pads
Qwiic / Stemma QT
External NOR Flash 64MB
drawn by: Dascalu Stefan-Nicolae
Battery Charge Level
OpenBook Schematic
EPD Power
Environmental Sensor BME688
SD Card
ESP32 C6
Li-Po Battery Charging Controller
E-Paper Display Header
SPI ESD Protection Lines
LDO Voltage Regulator
Voltage Supervisor + Reset & Boot / IO Button
E-Paper Drive Circuit
RTC Module DS3231SN

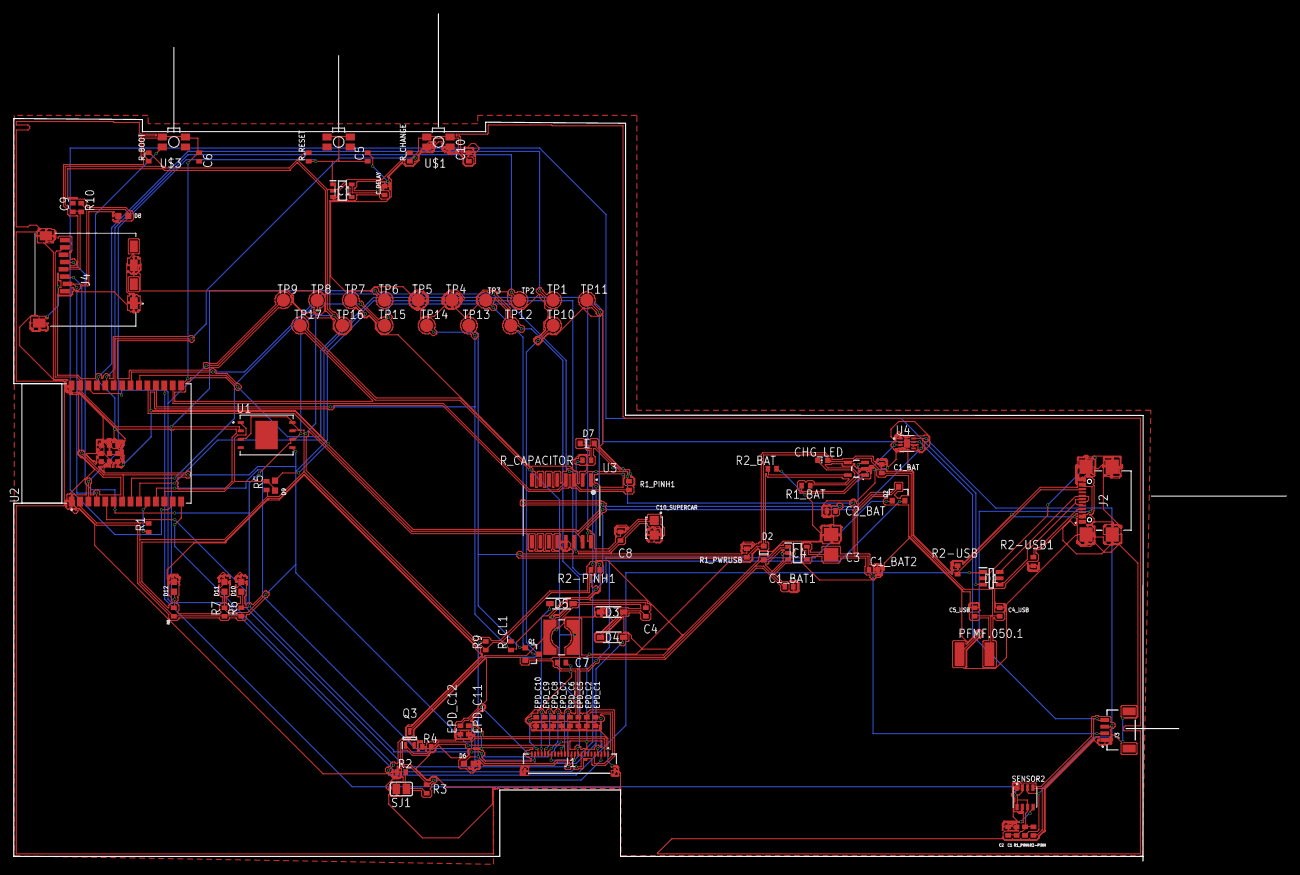
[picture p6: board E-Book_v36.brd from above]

Board: 2 copper layers, 191.8 x 127.7 mm, 103 parts (0 on the bottom side), 55 nets.

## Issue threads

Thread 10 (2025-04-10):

Eroare PCB

robertnen, 2025-04-10:
Apare o eroare Air Wire Unrouted. S-ar putea crea probleme.

stefan-dascalu, 2025-04-10:
A fost rezolvata intr-un issue anterior.

robertnen, 2025-04-10:
Am actualizat și am observat că a fost tratată eroarea.

Closed 2025-04-10.

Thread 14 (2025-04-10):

Schematicul din proiect are titlul său peste chenar

robertnen, 2025-04-10:
Fișierul cu probleme este acesta: [E-Book_v26.sch](https://github.com/stefan-dascalu/Proiect-TSC/blob/main/Hardware/E-Book_v26.sch)

stefan-dascalu, 2025-04-10:
S-a rezolvat.

Closed 2025-04-10.

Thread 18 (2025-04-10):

Posibil semnal neclar în diagramă

robertnen, 2025-04-10:
La SPI văd că e în diagonală. Cred ca ar fi bine să se vadă folosind unghiuri de 90 de grade. Imaginea cu probleme: [diagrama.png](https://github.com/stefan-dascalu/Proiect-TSC/blob/main/Images/diagrama.png)

stefan-dascalu, 2025-04-10:
Done.

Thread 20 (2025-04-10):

Probleme Silkscreen pe PCB

robertnen, 2025-04-10:
Pe PCB textele apar pe rute sau departe de piese.

stefan-dascalu, 2025-04-13:
S-a facut intr-un issue anterior.

Closed 2025-04-13.

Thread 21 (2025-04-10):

Probleme ESP32

robertnen, 2025-04-10:
Nu a fost decupat spațiul de sub componentă și există rutare pe zona respectivă.

stefan-dascalu, 2025-04-13:
Am rezolvat.

Closed 2025-04-13.

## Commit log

2025-04-06 Rename E-Book v9.csv to BillofMaterials.csv
    [BillofMaterials.csv]
2025-04-06 Update and rename PnP_E-Book v9_front.csv to PickandPlace.csv
    [PickandPlace.csv]

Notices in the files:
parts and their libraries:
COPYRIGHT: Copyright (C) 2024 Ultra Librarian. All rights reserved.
